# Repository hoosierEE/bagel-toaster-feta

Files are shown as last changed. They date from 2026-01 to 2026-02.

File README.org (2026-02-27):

* BB Triple Combo
KiCad projects files for a 3-in-1 effect pedal:
1. boost
2. overdrive/distoriton
3. fuzzy octave up

Each of these circuits is an original analog design by me.
Each effect can be independently engaged or bypassed via 3 footswitches, and there is a toggle to change the order of the boost (first or last) so you can have either:

#+begin_src 
boost → distortion → octave
#+end_src
 
or:

#+begin_src 
distortion → octave → boost 
#+end_src

Finally, there is a "sag" control to starve the pedal of power. No idea what that will sound like yet as I've not even prototyped it. In theory it should increase distortion and maybe add some subtle compression type effect.

Called "BB Triple Combo" because the overall design was at the request of an internet friend with these initials.

** Boost
Despite having the most clipping diodes of any effect in this bundle, the boost is clean-ish. It's a non-inverting op-amp based boost with LEDs in the feedback loop (like a Tube Screamer) but the gain is dept low so these diodes rarely have an effect. Their purpose is mostly to prevent the opamp from clipping on large inputs. After the op-amp, there is also a diodes-to-ground clipping section, similar to an MXR Distortion+ effect. But rather than causing distortion, these diodes add a supposedly tube-like smidge of dynamic harmonic content. Credit for this concept goes to the wizards at RunOffGroove and their [[https://www.runoffgroove.com/thunderbird.html][Thunderbird]] design.

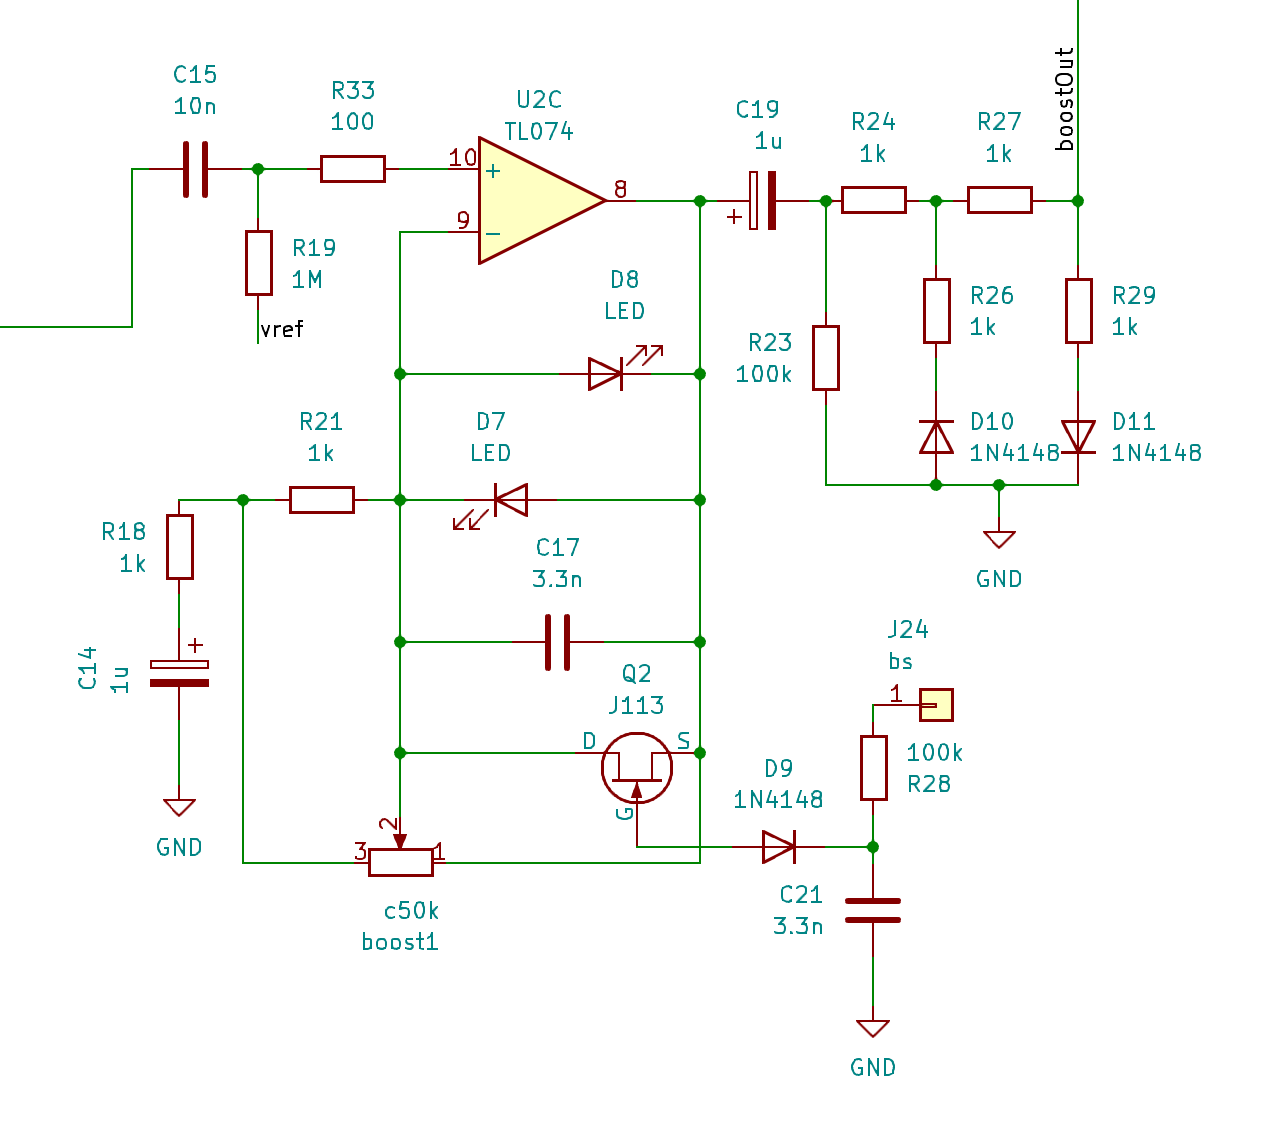
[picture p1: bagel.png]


Controls:
- gain

** Distortion
This distortion design eschews most guitar distortion design sensibilities. The signal path starts with a high-impedance buffer to preserve your guitar's high frequencies. Next comes an inverting soft clipping stage with a unique voltage divider gain control. This gain control arrangement permits a wide range of gain adjustment (11dB-40dB) despite using a mere 50k potentiometer in the feedback loop (lower resistance means less thermal noise).

#+begin_quote
One note regarding the schematic. The current-limiting resistor in series with the clipping diodes can be anywhere from 1k to 10k depending on mood. The original value (10k) encourages a softer clipping sound whereas lower values down to 1k will be harsher and more aggressive.
#+end_quote

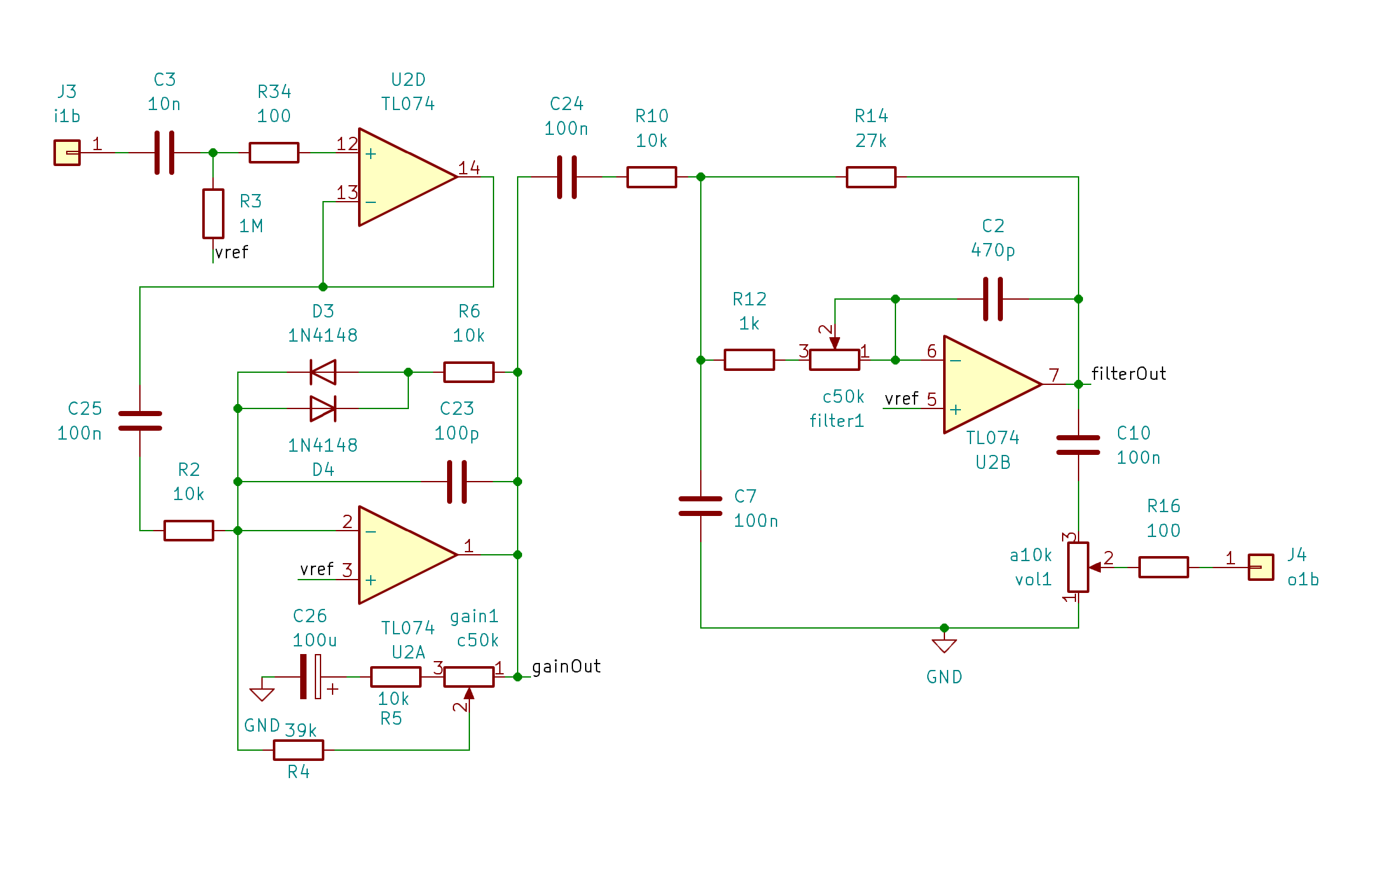
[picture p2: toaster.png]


From there the signal goes through a 2nd-order lowpass filter with a range of adjustment from 500Hz to 2.6kHz. This isn't a large range of sweep but the 12dB/octave slope makes it feel like it covers more sonic ground. This kind of filter is more typically found on analog synthesizer equipment, but I think it works well for guitar.

Controls from left to right:
- volume
- filter
- gain

** Octave Fuzz
This effect started as an experiment in making a "squarer" circuit. Up front is a JFET buffer and two high-gain CMOS inverter stages. The squarer concept is realized by splitting this amplified signal into two paths and routing each through a pair of series diodes pointed in opposite directions. The negative signal routes straight into the output mixer, while the positive signal gets inverted and then routes through an adjustable potentiometer labeled "Splat" and some series resistance and capacitance. The Splat control allows you to adjust the character of the octave effect - more pronounced octave in one direction, and more compressed and spongy in the other direction.

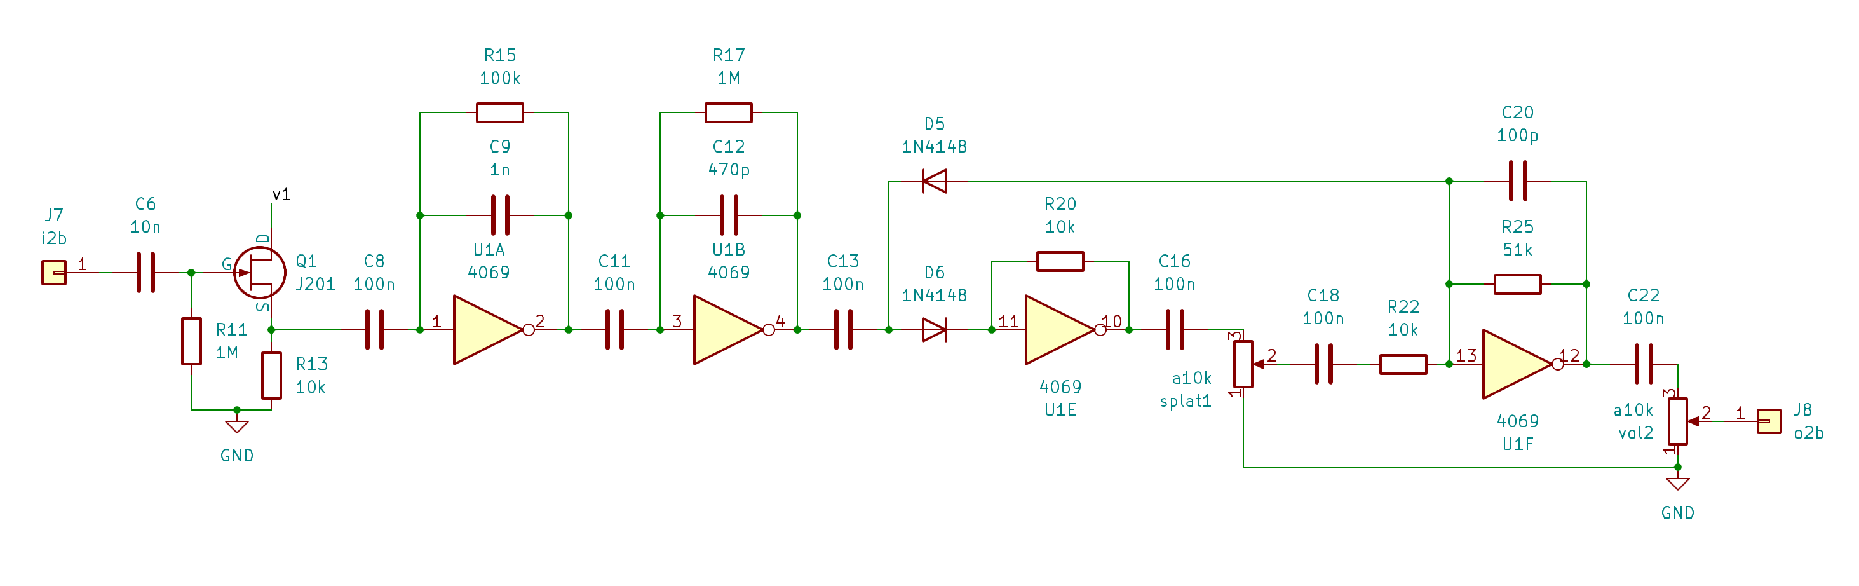
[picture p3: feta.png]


Controls from top to bottom:
- volume
- splat

* Circuit Board Layout
This is the largest design I've made in KiCad's PCB layout tool to date and I was proud of getting all the traces on a single layer.

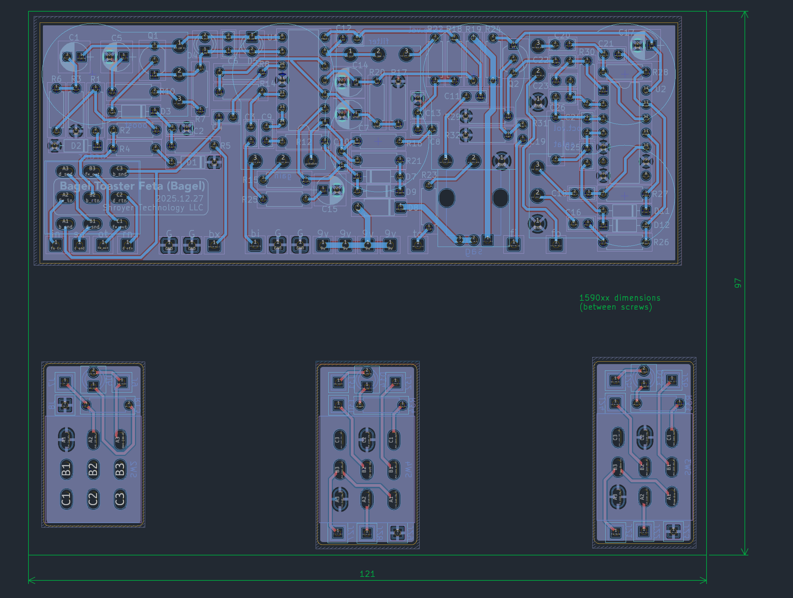
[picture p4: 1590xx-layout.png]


Eventually I changed to dual layer because it let me make the board more compact and route some traces more cleanly.
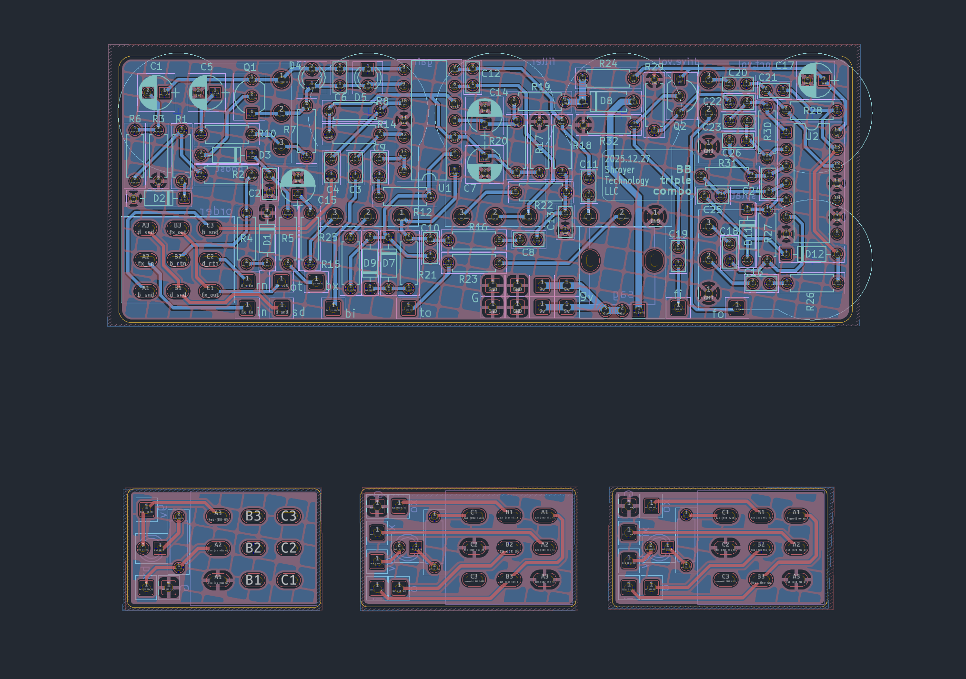
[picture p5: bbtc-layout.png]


KiCad is quirky and frustrating at first, but it's growing on me. The 3d rendering tool is especially cool.

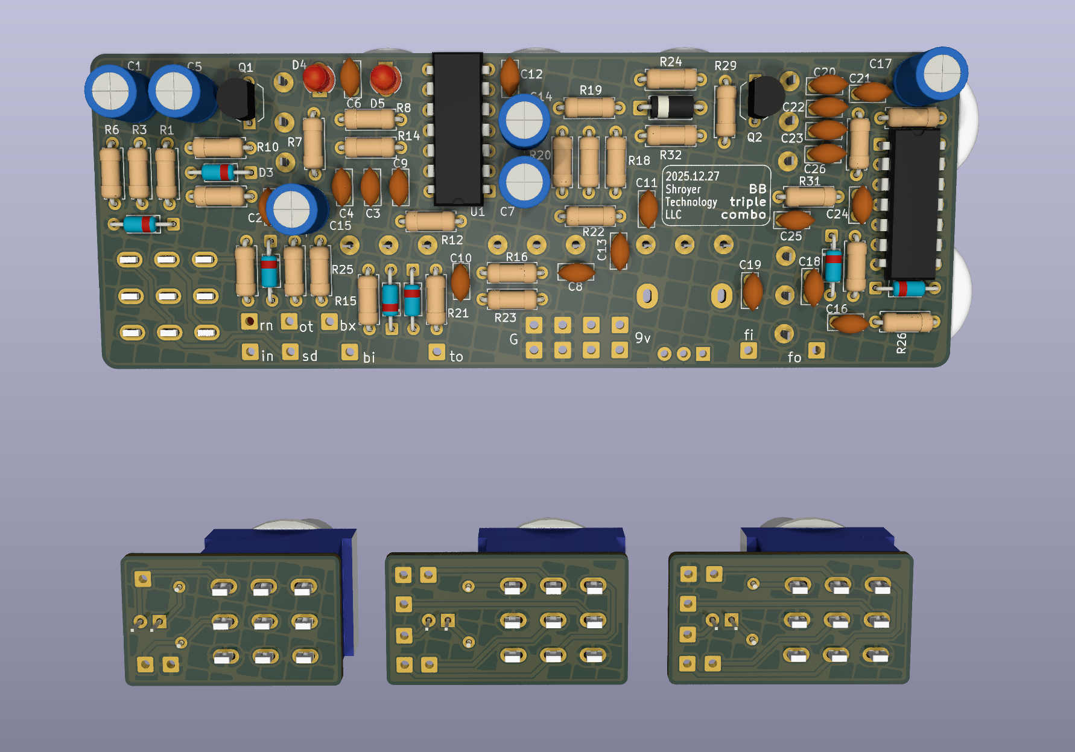
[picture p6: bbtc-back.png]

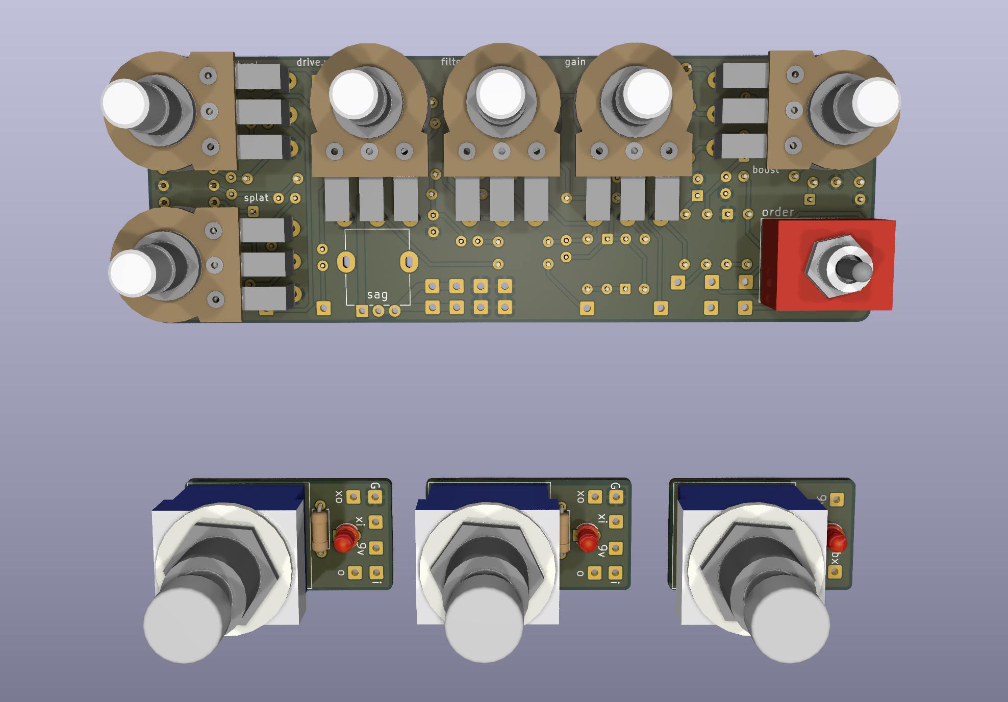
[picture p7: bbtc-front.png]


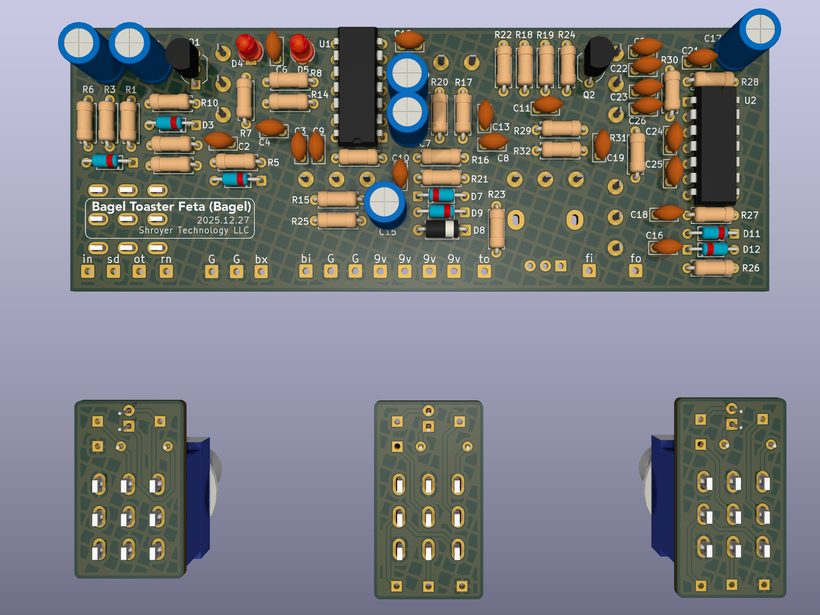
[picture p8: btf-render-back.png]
# 
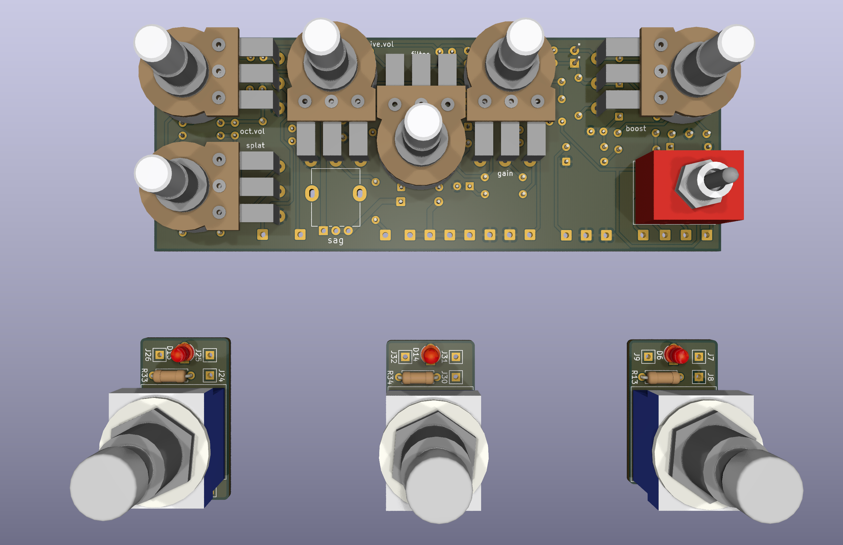
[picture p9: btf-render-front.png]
# 

+Next step is to have the board fabricated. I used OSH Park last time and the results were good but not fast. Might try a different one this time.+

Currently being fabbed by OSH Park. Hope it turns out as good as the last board.

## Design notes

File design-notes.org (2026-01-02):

#+title: Design Notes

From BB:

#+begin_quote
Ok so here is a pedal I’ve been dreaming up. There are a combination of tones I love, J Mascis of Dino Jr, Neil Young, David Gilmour, early Soundgarden and smashing pumpkins, Lee Renaldo of SY and of course good ole Jerry Garcia. So in a single pedal being able to mix and blend those to a unique tone.

So like a combo clean boost, distortion, fuzz octave. What would be cool is to have the ability to toggle the those 3 components on or off, switch the boost from being the first or last part of the path, let the distortion and fuzz octaver sit in the center of it all. And maybe even the ability to toggle in like voltage slag. There’s a Universal Audio preamp I used in grad school that had a vintage switch that would add some harmonic distortion and compression that also gave a little sag and made me think of having that. 
#+end_quote

Whether the effects I designed meet this brief or not remains to be seen, but so far I've implemented all of these except the voltage sag feature. That will require some experimentation. When I've seen people implement a voltge "sag" feature it's usually done by adding resistance in series with the power supply. But if you do that for multiple effects all sharing the same power supply, they might feed back into each other. That would generally sound bad, though the large bypass capacitors would limit the effect.

The other thing to consider is where to put such a control. I've got a board layout designed around 6 board-mounted potentiometers. There is room to add an additional pot between the distortion and octave, so physical placement wouldn't be difficult.

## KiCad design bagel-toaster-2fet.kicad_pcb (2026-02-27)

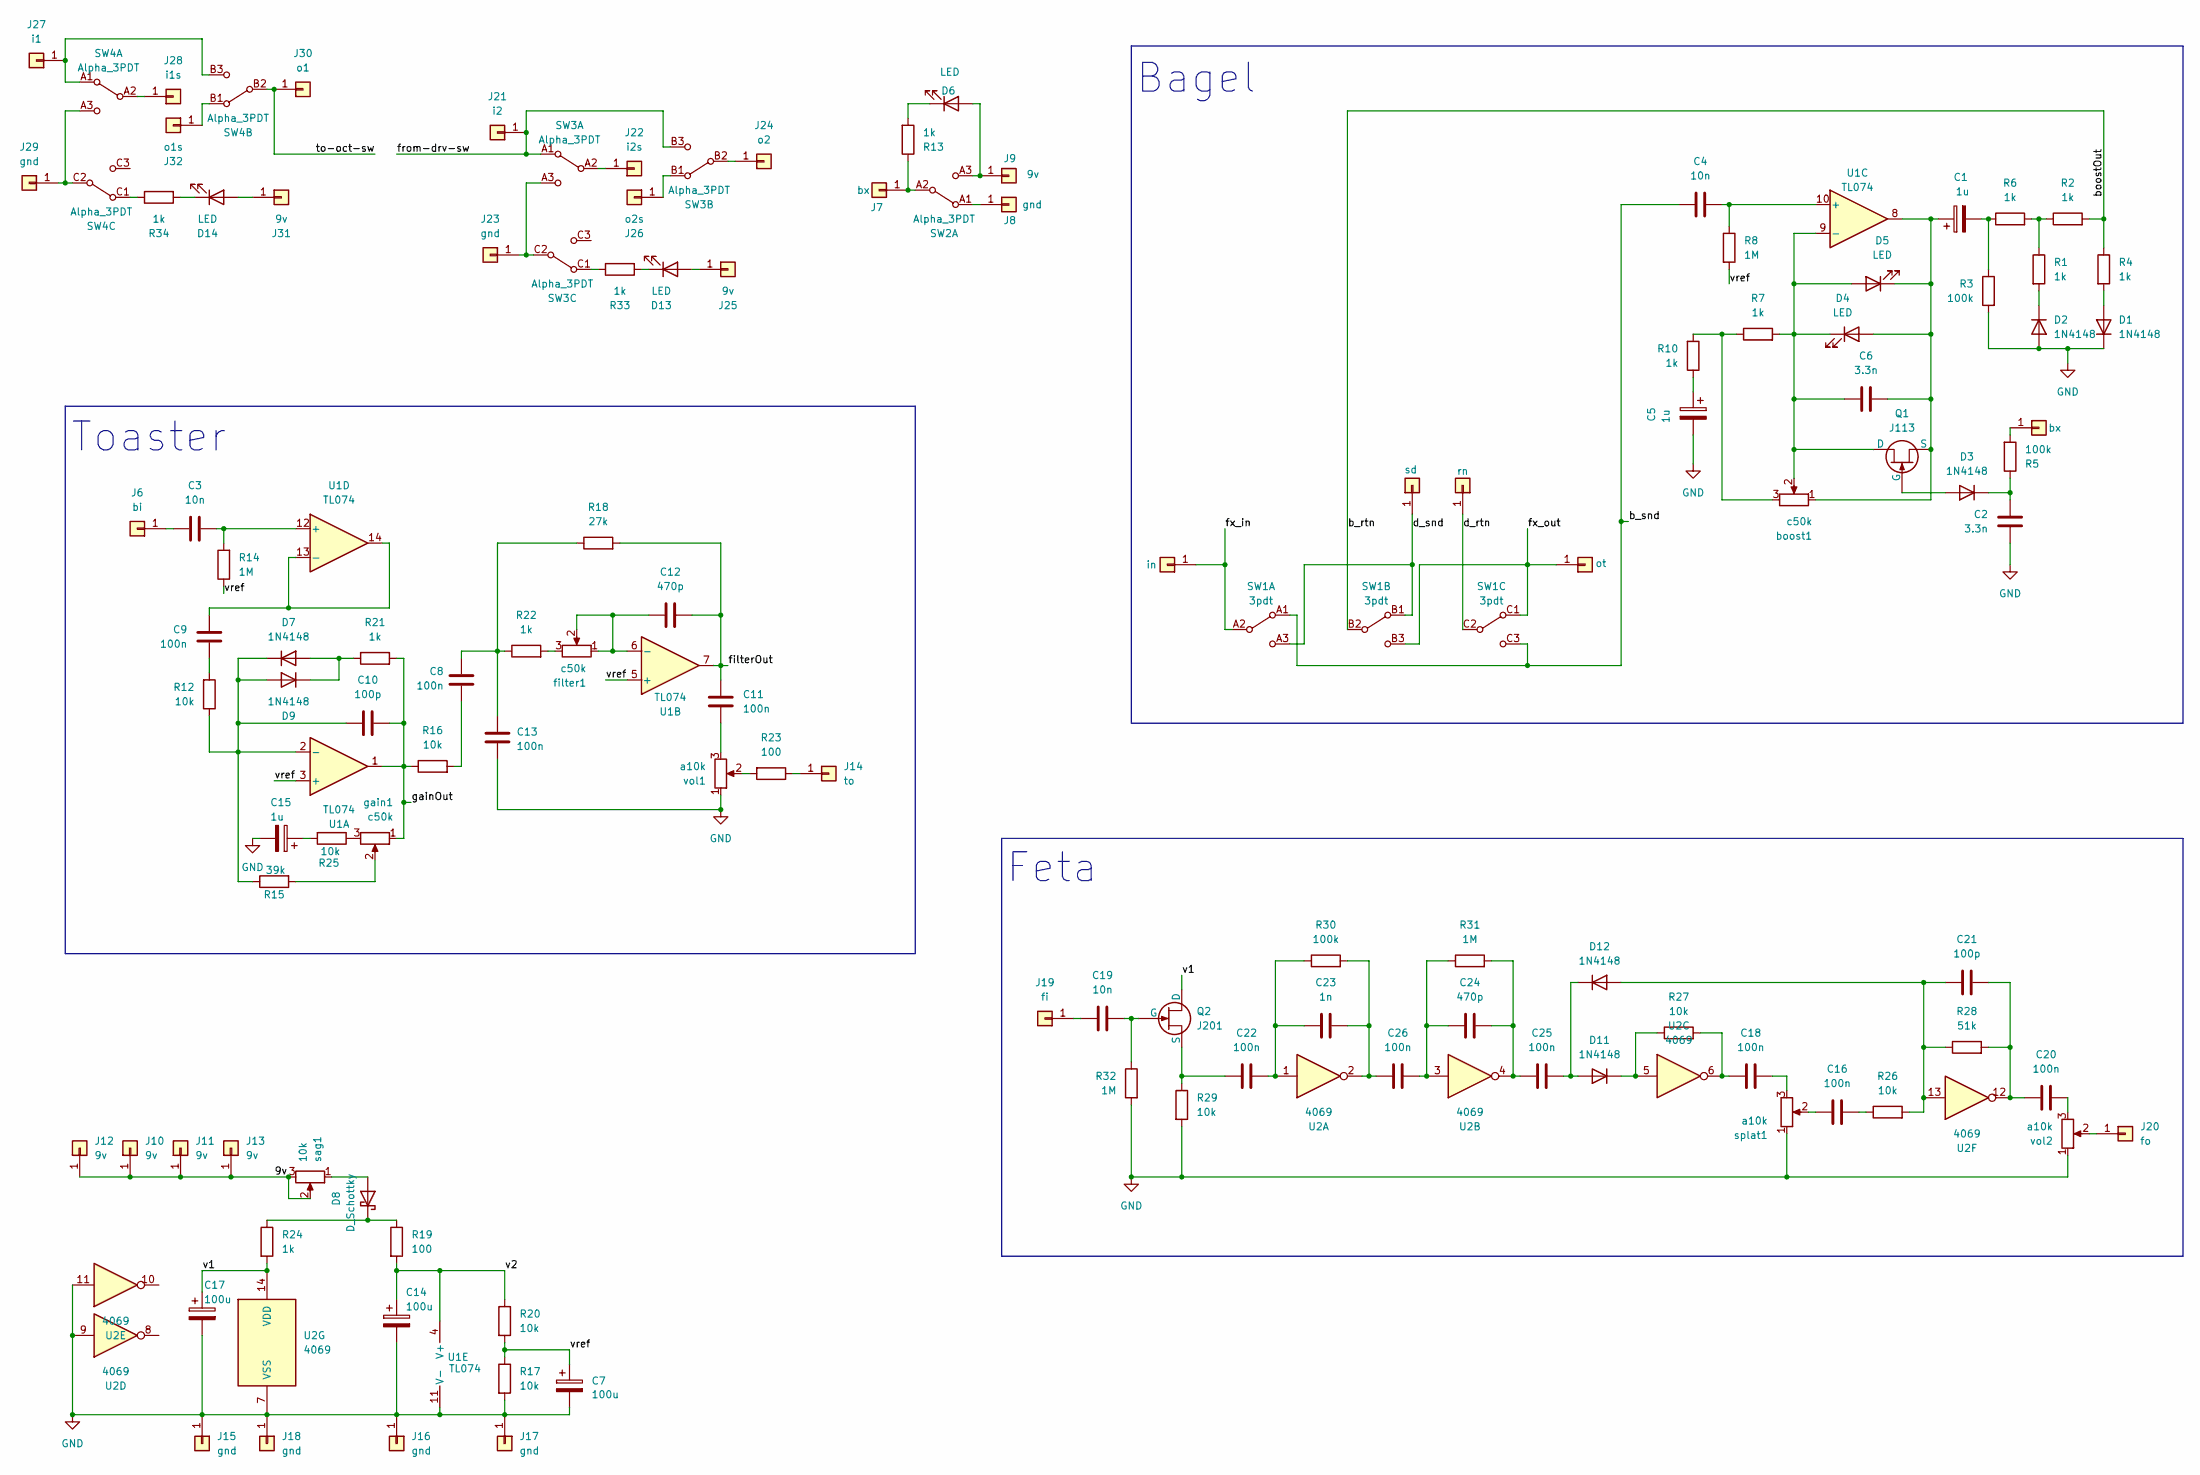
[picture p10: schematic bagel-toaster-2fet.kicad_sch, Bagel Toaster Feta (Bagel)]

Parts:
C1, C5, C15: 1u; CP_ELCO_1x2_S
C2, C6: 3.3n; C_CERAMIC_1x2
C3, C4, C19: 10n; C_CERAMIC_1x2
C7, C14, C17: 100u; CP_ELCO_1x2_S
C8, C9, C11, C13, C16, C18, C20, C22, C25, C26: 100n; C_CERAMIC_1x2
C10, C21: 100p; C_CERAMIC_1x2
C12, C24: 470p; C_CERAMIC_1x2
C23: 1n; C_CERAMIC_1x2
D1, D2, D3, D7, D9, D11, D12: 1N4148; D_DO-35_SOD27_P7.62mm_Horizontal
D4, D5, D6, D13, D14: LED; LED_3.0mm
D8: D_Schottky; D_A-405_P7.62mm_Horizontal
J1, J7: bx; SolderWire-0.5sqmm_1x01_D0.9mm_OD2.1mm
J2: do_snd; SolderWire-0.5sqmm_1x01_D0.9mm_OD2.1mm
J3: out; SolderWire-0.5sqmm_1x01_D0.9mm_OD2.1mm
J4: in; SolderWire-0.5sqmm_1x01_D0.9mm_OD2.1mm
J5: do_rtn; SolderWire-0.5sqmm_1x01_D0.9mm_OD2.1mm
J6: bi; SolderWire-0.5sqmm_1x01_D0.9mm_OD2.1mm
J8, J15, J16, J17, J18, J23, J29: gnd; SolderWire-0.5sqmm_1x01_D0.9mm_OD2.1mm
J9, J10, J11, J12, J13, J25, J31: 9v; SolderWire-0.5sqmm_1x01_D0.9mm_OD2.1mm
J14: to; SolderWire-0.5sqmm_1x01_D0.9mm_OD2.1mm
J19: fi; SolderWire-0.5sqmm_1x01_D0.9mm_OD2.1mm
J20: fo; SolderWire-0.5sqmm_1x01_D0.9mm_OD2.1mm
J21: i2; SolderWire-0.5sqmm_1x01_D0.9mm_OD2.1mm
J22: i2s; SolderWire-0.5sqmm_1x01_D0.9mm_OD2.1mm
J24: o2; SolderWire-0.5sqmm_1x01_D0.9mm_OD2.1mm
J26: o2s; SolderWire-0.5sqmm_1x01_D0.9mm_OD2.1mm
J27: i1; SolderWire-0.5sqmm_1x01_D0.9mm_OD2.1mm
J28: i1s; SolderWire-0.5sqmm_1x01_D0.9mm_OD2.1mm
J30: o1; SolderWire-0.5sqmm_1x01_D0.9mm_OD2.1mm
J32: o1s; SolderWire-0.5sqmm_1x01_D0.9mm_OD2.1mm
Q1: J113; TO-92_W
Q2: J201; TO-92_W
R1, R2, R4, R6, R7, R10, R13, R21, R22, R24, R33, R34: 1k; R_1x4
R3, R5, R30: 100k; R_1x4
R8, R14, R31, R32: 1M; R_1x4
R12, R16, R17, R20, R25, R26, R27, R29: 10k; R_1x4
R15: 39k; R_1x4
R18: 27k; R_1x4
R19, R23: 100; R_1x4
R28: 51k; R_1x4
SW1: 3pdt; 3pdt-toggle
SW2, SW3, SW4: Alpha_3PDT; 3pdt
U1: TL074; DIP-14_W7.62mm
U2: 4069; DIP-14_W7.62mm
boost1: c50k; pot-16mm-short-leg
filter1: c50k; pot-16mm-short-leg
gain1: c50k; pot-16mm-short-leg
sag1: 10k; Potentiometer_Alpha_RD901F-40-00D_Single_Vertical
splat1: a10k; pot-16mm-short-leg
vol1, vol2: a10k; pot-16mm-short-leg

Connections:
/9v: J10.1, J11.1, J12.1, J13.1, sag1.2, sag1.3
/b_rtn: R2.2, R4.1, SW1.B2
/b_snd: C4.1, SW1.A1, SW1.C3
/d_rtn: J5.1, SW1.C2
/d_snd: J2.1, SW1.A3, SW1.B1
/filterOut: C11.1, C12.2, R18.2, U1.7
/from-drv-sw: J21.1, SW3.A1, SW3.B3
/fx_in: J4.1, SW1.A2
/fx_out: J3.1, SW1.B3, SW1.C1
/gainOut: C10.2, R16.1, R21.2, U1.1, gain1.1
/to-oct-sw: J30.1, SW4.B2
/v1: C17.1, Q2.1 (D), R24.2, U2.14 (VDD)
/v2: C14.1, R19.2, R20.1, U1.4 (V+)
/vref: C7.1, R8.2, R14.1, R17.1, R20.2, U1.3 (+), U1.5 (+)
GND: C2.1, C5.2, C7.2, C13.1, C14.2, C15.2, C17.2, D1.1 (K), D2.2 (A), J15.1, J16.1, J17.1, J18.1, R3.2, R17.2, R29.2, R32.2, U1.11 (V-), U2.7 (VSS), U2.9, U2.11, splat1.1, vol1.1, vol2.1
unnamed: C1.2, R3.1, R6.1
unnamed: C5.1, R10.1
unnamed: C8.2, R16.2
unnamed: C9.1, R12.2
unnamed: C11.2, vol1.3
unnamed: C8.1, C13.2, R18.1, R22.1
unnamed: C15.1, R25.2
unnamed: C16.1, R26.1
unnamed: C16.2, splat1.2
unnamed: C18.1, R27.2, U2.6
unnamed: C18.2, splat1.3
unnamed: C20.1, C21.2, R28.2, U2.12
unnamed: C20.2, vol2.3
unnamed: C22.2, C23.1, R30.1, U2.1
unnamed: C23.2, C26.1, R30.2, U2.2
unnamed: C24.1, C26.2, R31.1, U2.3
unnamed: C24.2, C25.1, R31.2, U2.4
unnamed: D1.2 (A), R4.2
unnamed: D2.1 (K), R1.2
unnamed: D3.2 (A), Q1.2 (G)
unnamed: C2.2, D3.1 (K), R5.1
unnamed: C1.1, C6.2, D4.2 (A), D5.1 (K), Q1.3 (S), U1.8, boost1.1
unnamed: C6.1, D4.1 (K), D5.2 (A), Q1.1 (D), R7.2, U1.9 (-), boost1.2
unnamed: D6.2 (A), J9.1, SW2.A3
unnamed: D6.1 (K), R13.2
unnamed: D7.2 (A), D9.1 (K), R21.1
unnamed: C10.1, D7.1 (K), D9.2 (A), R12.1, R15.1, U1.2 (-)
unnamed: D8.2 (A), sag1.1
unnamed: D8.1 (K), R19.1, R24.1
unnamed: C25.2, D11.2 (A), D12.1 (K)
unnamed: D11.1 (K), R27.1, U2.5
unnamed: C21.1, D12.2 (A), R26.2, R28.1, U2.13
unnamed: D13.2 (A), J25.1
unnamed: D13.1 (K), R33.2
unnamed: D14.2 (A), J31.1
unnamed: D14.1 (K), R34.2
unnamed: J1.1, R5.2
unnamed: C3.1, J6.1
unnamed: J7.1, R13.1, SW2.A2
unnamed: J8.1, SW2.A1
unnamed: J14.1, R23.1
unnamed: C19.1, J19.1
unnamed: J20.1, vol2.2
unnamed: J22.1, SW3.A2
unnamed: J23.1, SW3.A3, SW3.C2
unnamed: J24.1, SW3.B2
unnamed: J26.1, SW3.B1
unnamed: J27.1, SW4.A1, SW4.B3
unnamed: J28.1, SW4.A2
unnamed: J29.1, SW4.A3, SW4.C2
unnamed: J32.1, SW4.B1
unnamed: C19.2, Q2.2 (G), R32.1
unnamed: C22.1, Q2.3 (S), R29.1
unnamed: R1.1, R2.1, R6.2
unnamed: R7.1, R10.2, boost1.3
unnamed: R15.2, gain1.2
unnamed: R22.2, filter1.3
unnamed: R23.2, vol1.2
unnamed: R25.1, gain1.3
unnamed: R33.1, SW3.C1
unnamed: R34.1, SW4.C1
unnamed: C12.1, U1.6 (-), filter1.1, filter1.2
unnamed: C4.2, R8.1, U1.10 (+)
unnamed: C3.2, R14.2, U1.12 (+)
unnamed: C9.2, U1.13 (-), U1.14

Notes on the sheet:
Toaster
Bagel
Feta

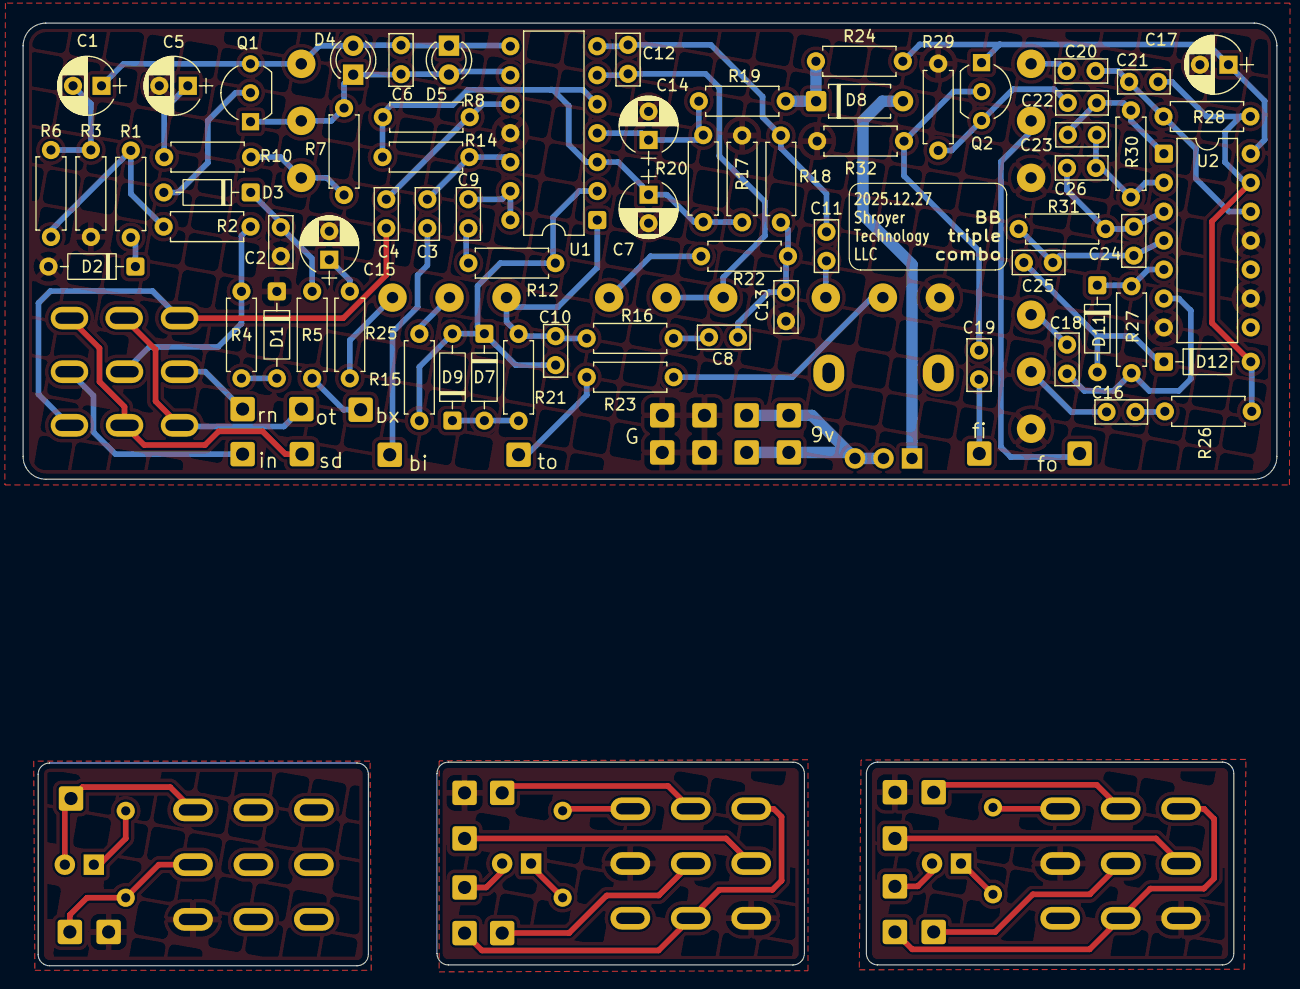
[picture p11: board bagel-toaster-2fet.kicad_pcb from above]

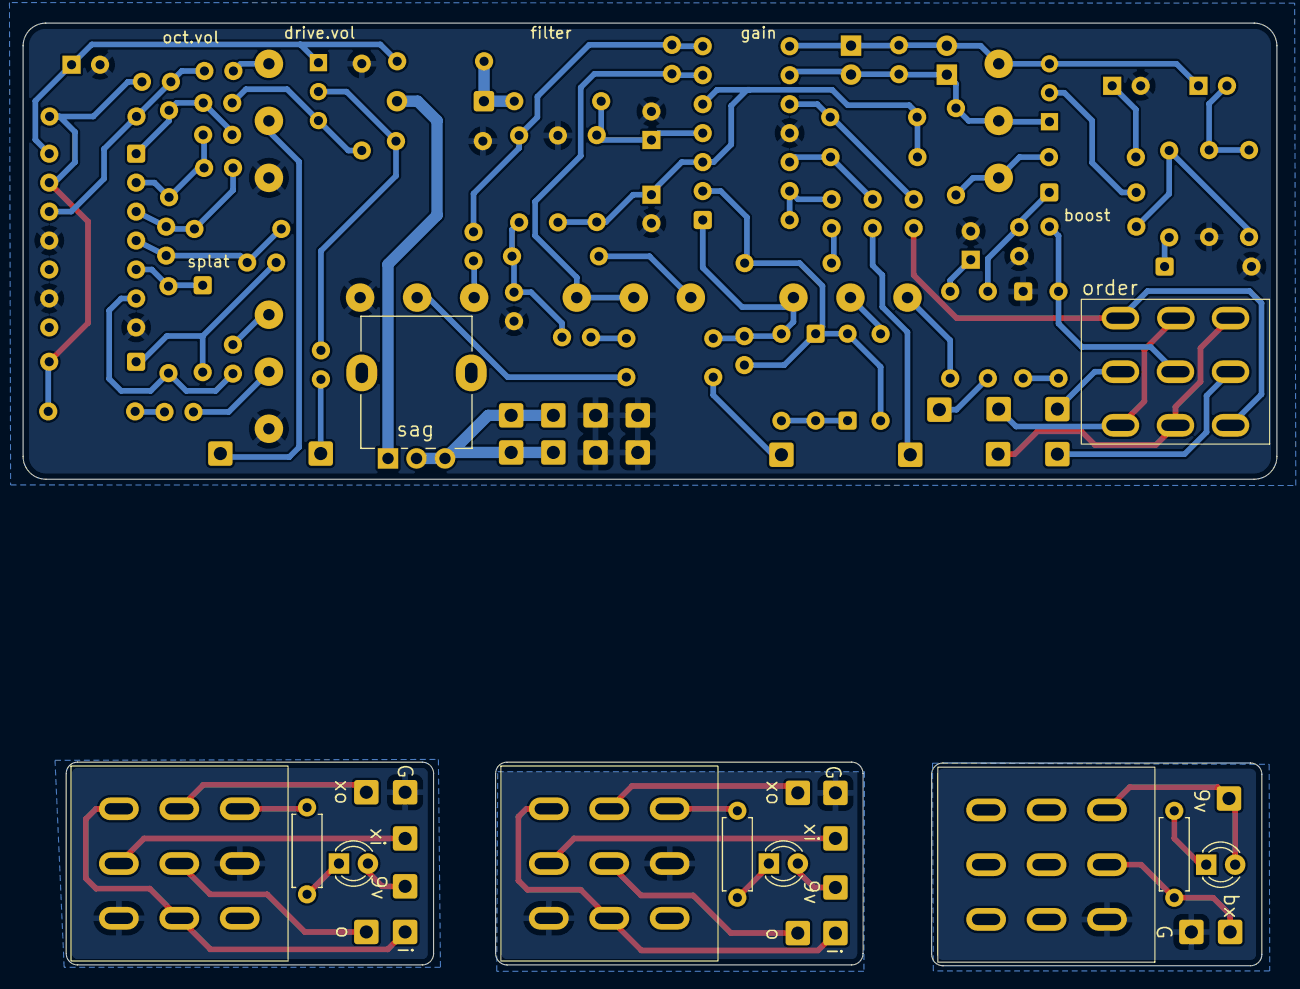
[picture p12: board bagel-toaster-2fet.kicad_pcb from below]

Board: 2 copper layers, 110.0 x 82.7 mm, 118 parts (32 on the bottom side), 80 nets.

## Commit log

2026-01-02 add sag control and reannotate
    [bagel-toaster-2fet.kicad_pcb, bagel-toaster-2fet.kicad_sch]
2026-01-02 more gitignore for KiCad
2026-01-03 update annotations
    [bagel-toaster-2fet.kicad_sch]
2026-01-03 16mm pot refactor done
    [bagel-toaster-2fet.kicad_pcb, bagel-toaster-2fet.kicad_sch]
2026-01-12 one sided and smaller
    [bagel-toaster-2fet.kicad_pcb, bagel-toaster-2fet.kicad_sch]
2026-02-15 looking pretty good
    [bagel-toaster-2fet.kicad_pcb]
2026-02-17 remove old images
    [bagel-toaster-2fet.kicad_pcb]
2026-02-27 oh yeah save
    [bagel-toaster-2fet.kicad_pcb]
2026-02-27 note current limiting resistor
